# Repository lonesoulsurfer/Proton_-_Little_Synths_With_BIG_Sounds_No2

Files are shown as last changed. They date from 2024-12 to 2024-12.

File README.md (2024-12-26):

# Proton - Little Synths With BIG Sounds #2



This is the 2nd in a series of little synths that I'll be publishing over the next couple builds. Like my Elements synth, I've kept everything as simple as possible on this build so anyone with a soldering iron and basic soldering skills can make it. I've done away with a case and fancy power supplies to keep the build simple.

Props to Synther Jack (https://syntherjack.net/totoro-1-ic-simple-synth/) who designed this amazing little synth. All I've done is redesigned the PCB and created a front panel. I've also done a couple of mods and have included these on this build. Please check out Synther Jacks write up if you want a thorough run through on how the synth works.

The synth runs off 1 IC which is an incredible feat when you consider the amazing sounds this beast can produce. The other amazing thing about this synth is it only needs 2 X AA batteries to power it!

It's a blast to play with and can be connected to a sequencer which really shows off the sounds this little synth is capable of producing. If you don't have a sequencer then don't worry - it's still tonnes of fun to play.

Instructables step by step guide: https://www.instructables.com/Proton-Little-Synths-With-BIG-Sounds-2/

YouTube vid: https://www.youtube.com/watch?v=9Ci_B_42n48



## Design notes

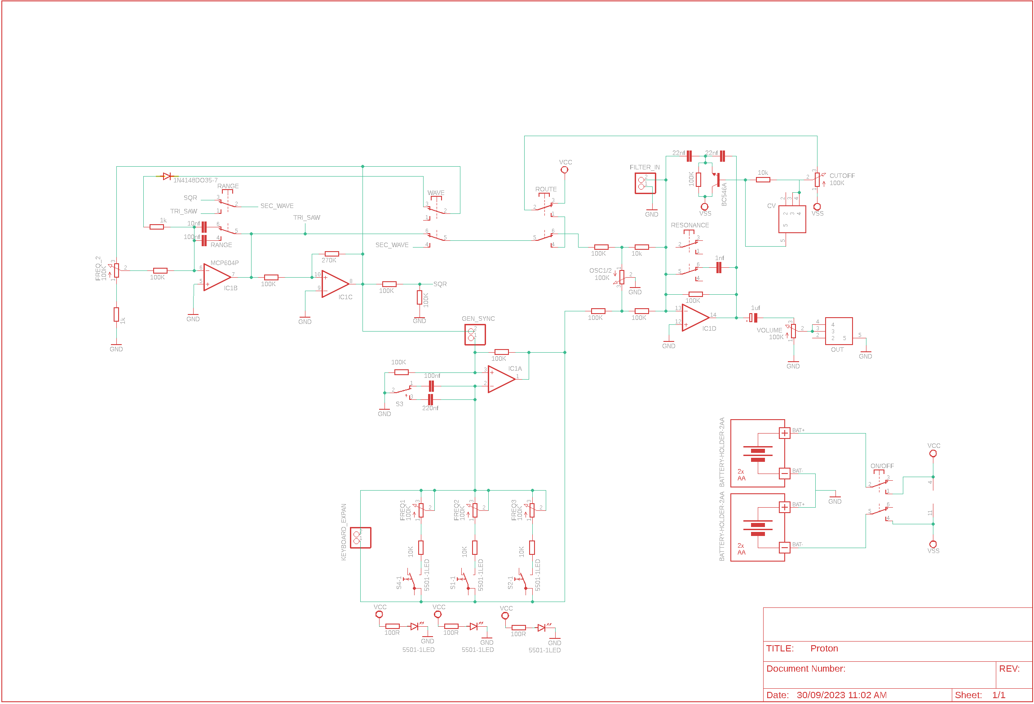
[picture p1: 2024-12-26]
Proton - Schematic.png

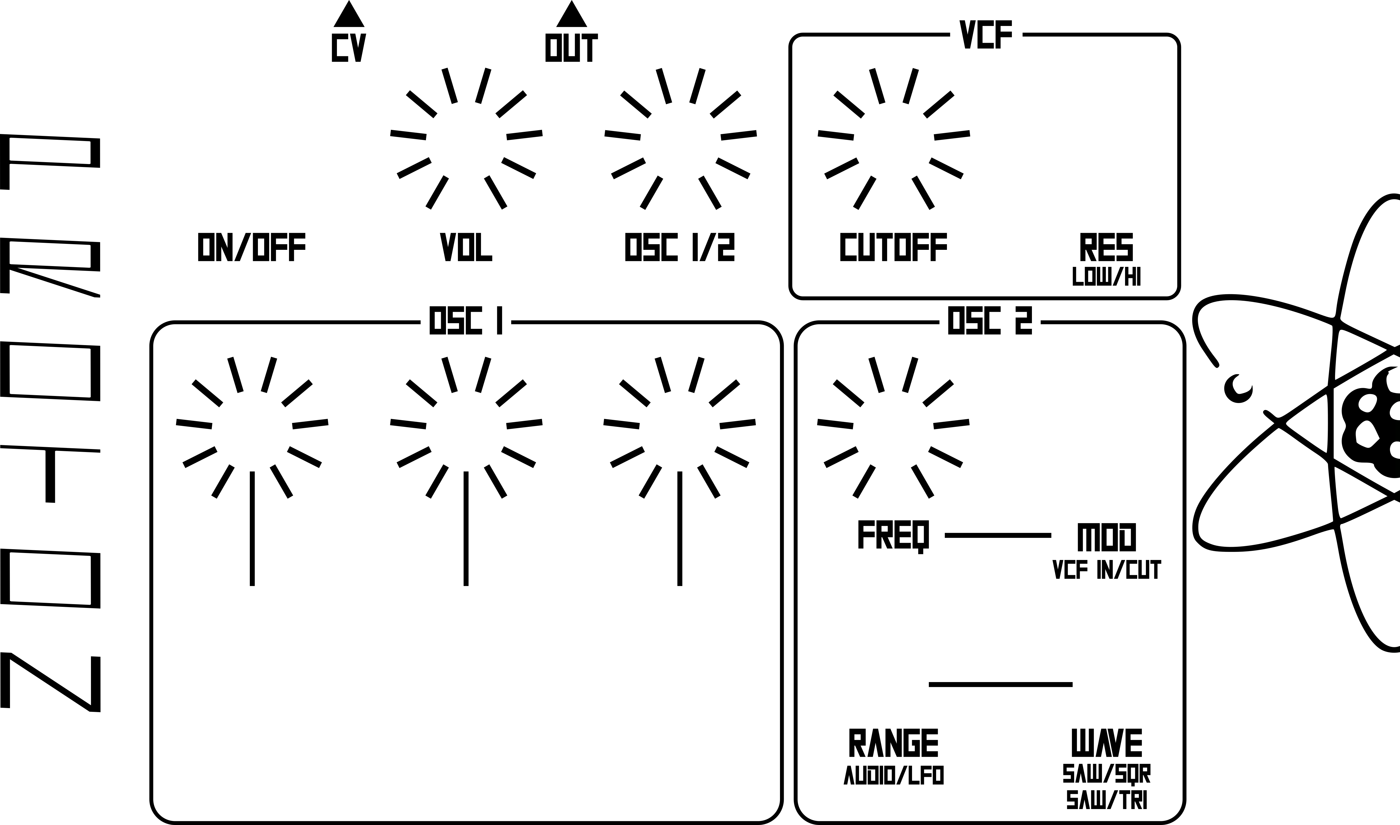
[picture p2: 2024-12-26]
Front Panel Design/Proton - Front Panel.png

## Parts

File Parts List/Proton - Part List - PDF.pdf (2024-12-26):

Part | Type | Value | Qty | Notes | Link | Image
Resistor | Metal Film | 100R | 3 | or just buy them in individual values | link (https://www.aliexpress.com/w/wholesale-resistor-assorted.html?spm=a2g0o.home.search.0) You can buy resistors in assorted lots
| | 1K | 2
| | 10K | 5
| | 100K | 11
| | 270K | 1
Capacitor | Polyester | 1nf | 1 | | link (https://www.aliexpress.com/item/1005001291687251.html?curPageLogUid=RXYDWYWPA8KV)
| | 10nf | 10
| | 22nf | 2
| | 100nf | 2
| | 220nf | 1

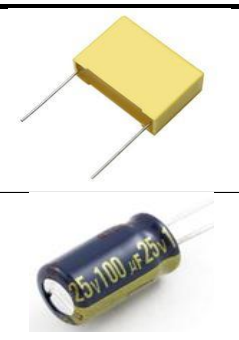
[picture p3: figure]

| electrolytic 16V | 1uf | 1 | any as long as it is over 9V | link (https://www.aliexpress.com/w/wholesale-capacitor-1uf-radial.html?spm=a2g0o.productlist.search.0)

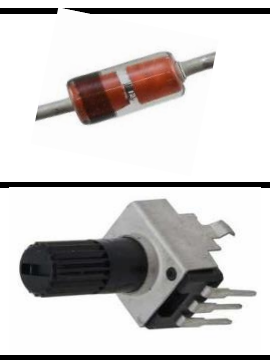
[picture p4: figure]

Diode | 1N4148 | | 1 | | link (https://www.aliexpress.com/w/wholesale-diode-1n4148.html?spm=a2g0o.productlist.search.0)
Potentiometer | 9 mm vertical | 100K | 7 | | link
Audio Jack | PCB Mount | PJ-320A | 2 | | link (https://www.aliexpress.com/item/1005002607946737.html)
IC | MCP6004 | | 1 | Through hole type. | link (https://www.ebay.com.au/sch/i.html?_from=R40&_trksid=p2332490.m570.l1313&_nkw=mcp6004&_sacat=0)
Switches | 6 Pin - 7mm | | 5 | | link (https://www.aliexpress.com/w/wholesale-6-PIN-SWITCH-7mm.html?spm=a2g0o.productlist.search.0)
| Momentary | | 3 | | link (https://www.aliexpress.com/item/1005005461429735.html)
| Slide Switch | | 1 | | link (https://www.aliexpress.com/item/1005005877515591.html?curPageLogUid=p5RxaHHfpDIU)
Transister | BC546 | | 1 | Can use 2N2222 | link (https://www.aliexpress.com/w/wholesale-BC546.html?spm=a2g0o.detail.search.0)
Battery Holder | PCB Mount | AA | 2 | | link (https://www.aliexpress.com/item/1005003776405167.html?curPageLogUid=Q4Qr7hw5smms)

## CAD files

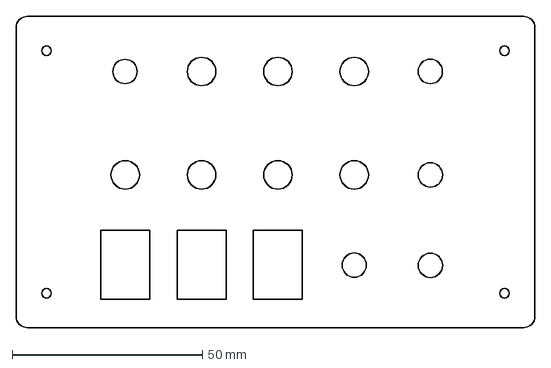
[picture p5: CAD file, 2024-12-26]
Front Panel Design/Proton Fusion - DXF.dxf
136.4 x 81.8 mm

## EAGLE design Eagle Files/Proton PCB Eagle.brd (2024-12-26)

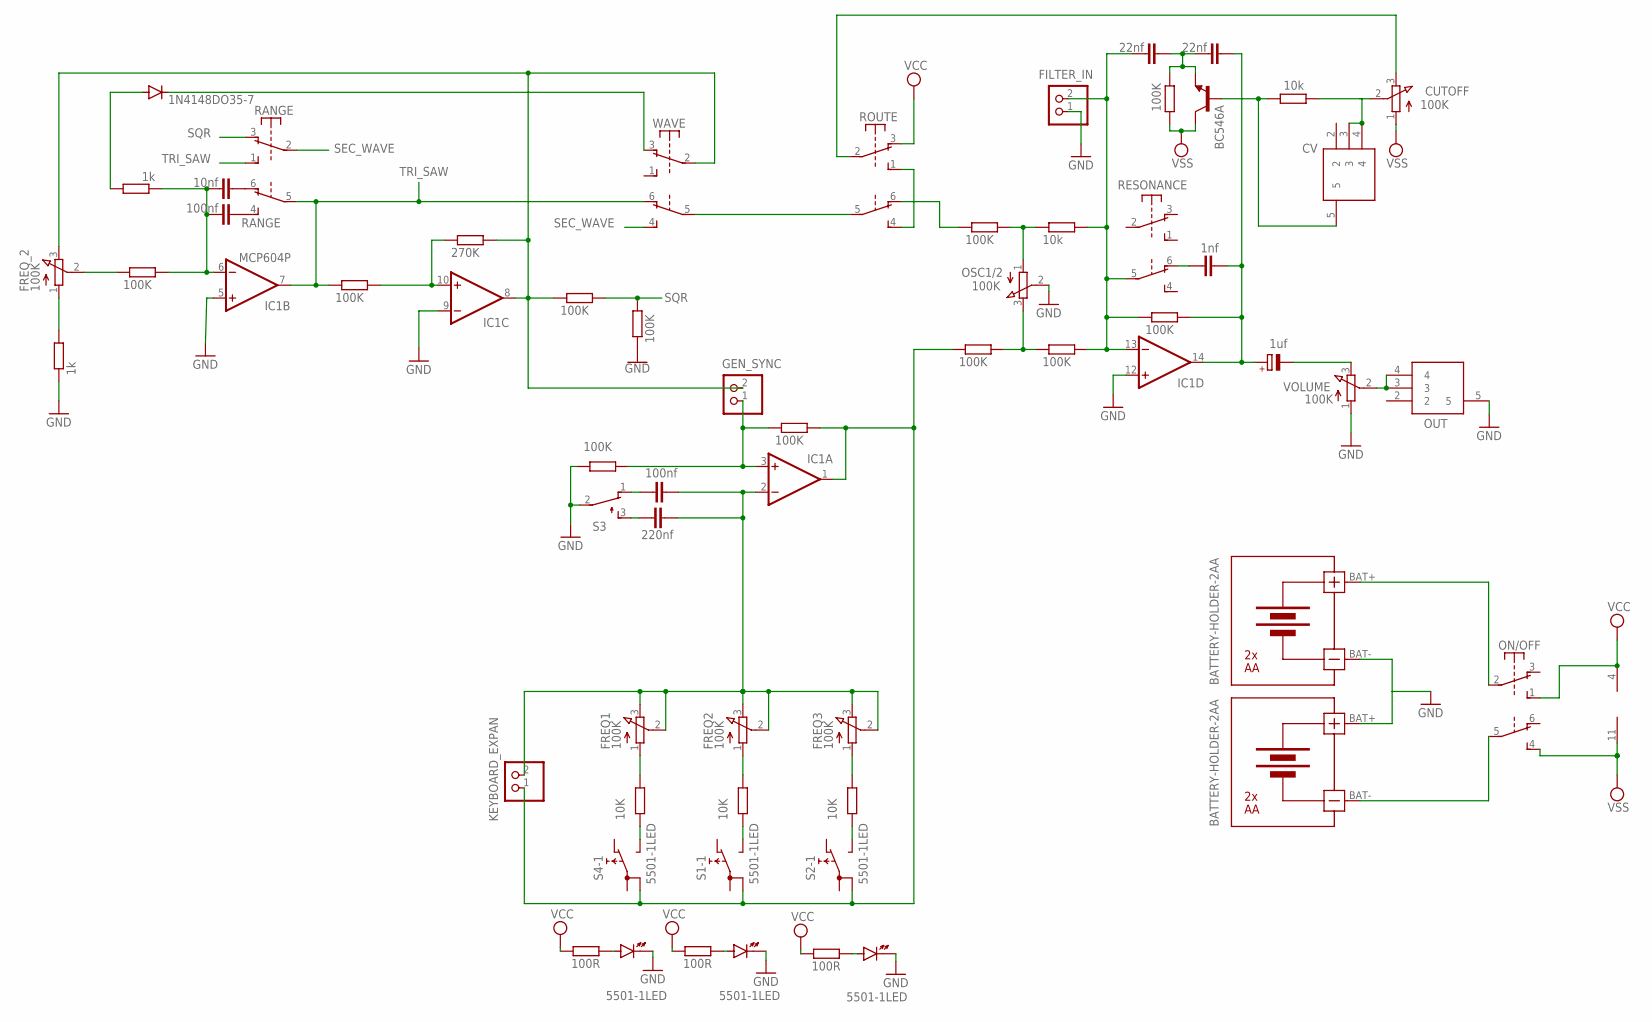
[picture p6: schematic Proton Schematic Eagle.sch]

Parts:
1K, 1K1: 1k; 0207/10
100K, 100K1, 100K3, 100K4, 100K5, 100K7, 100K8, 100K9, 100K11, 100K12, 100K13: 100K; 0207/10
100K2: 270K; 0207/10
100K6, 100K10: 10k; 0207/10
100K14, 100K15, 100K16: 10K; 0207/10
100K18, 100K19, 100K20: 100R; 0207/10
C1, C7: 100nf; C050-024X044
C2: 10nf; C050-024X044
C3, C4: 22nf; C050-024X044
C5: 1nf; C050-024X044
C6: 220nf; C050-024X044
C8: 1uf; E2,5-5
CUTOFF: 100K; EVUFXM
CV: PJ-320A; PJ320A
D1: 1N4148DO35-7; DO35-7
FILTER_IN: PINHD-1X2; 1X02
FREQ1, FREQ2, FREQ3: 100K; EVUFXM
FREQ_2: 100K; EVUFXM
GEN_SYNC: PINHD-1X2; 1X02
IC1: MCP604P; DIL14
KEYBOARD_EXPAN: PINHD-1X2; 1X02
ON/OFF: SWITCH-6PIN
OSC1/2: 100K; EVUFXM
OUT: PJ-320A; PJ320A
Q1: BC546A; TO92-EBC
RANGE: SWITCH-6PIN
RESONANCE: SWITCH-6PIN
ROUTE: SWITCH-6PIN
S1, S2, S4: 5501-1LED
S3: TL32YO; TL3XYO
U$1, U$2: BATTERY-HOLDER-2AA
VOLUME: 100K; EVUFXM
WAVE: SWITCH-6PIN

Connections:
GND: 1K.1, 100K4.1, 100K13.1, FILTER_IN.1, IC1.5 (+IN), IC1.9 (-IN), IC1.12 (+IN), OSC1/2.2 (S), OUT.5, S1.- (K), S2.- (K), S3.2, S4.- (K), U$1.BAT-, U$2.BAT+, VOLUME.1 (A)
unnamed: 100K1.2, 100K2.1, IC1.10 (+IN)
unnamed: 100K.1, FREQ_2.2 (S)
unnamed: 1K.2, FREQ_2.1 (A)
unnamed: C1.2, RANGE.4 (S)
unnamed: C2.2, RANGE.6 (O)
unnamed: 1K1.1, 100K.2, C1.1, C2.1, IC1.6 (-IN)
unnamed: ROUTE.5, WAVE.5
unnamed: 1K1.2, D1.A
unnamed: 100K2.2, 100K3.1, FREQ_2.3 (E), GEN_SYNC.2, IC1.8 (OUT), WAVE.2
unnamed: D1.C, WAVE.3 (O)
unnamed: ROUTE.1 (S), ROUTE.4 (S)
unnamed: 100K5.1, ROUTE.6 (O)
unnamed: 100K5.2, 100K6.1, OSC1/2.1 (A)
unnamed: 100K18.1, S4.+ (A)
unnamed: C8.-, VOLUME.3 (E)
unnamed: 100K9.2, C3.2, C4.1, Q1.E
unnamed: CUTOFF.3 (E), ROUTE.2
unnamed: C5.1, RESONANCE.6 (O)
unnamed: 100K11.2, C4.2, C5.2, C8.+, IC1.14 (OUT)
unnamed: 100K7.2, 100K8.1, OSC1/2.3 (E)
unnamed: 100K6.2, 100K8.2, 100K11.1, C3.1, FILTER_IN.2, IC1.13 (-IN), RESONANCE.5
unnamed: 100K19.1, S1.+ (A)
unnamed: 100K10.1, CV.5, Q1.B
unnamed: 100K20.1, S2.+ (A)
unnamed: 100K12.1, 100K13.2, GEN_SYNC.1, IC1.3 (+IN)
unnamed: ON/OFF.2, U$1.BAT+
unnamed: C6.2, C7.2, FREQ1.2 (S), FREQ1.3 (E), FREQ2.2 (S), FREQ2.3 (E), FREQ3.2 (S), FREQ3.3 (E), IC1.2 (-IN), KEYBOARD_EXPAN.2
unnamed: 100K14.1, S4.NO
unnamed: 100K15.1, S1.NO
unnamed: 100K16.1, S2.NO
unnamed: 100K7.1, 100K12.2, IC1.1 (OUT), KEYBOARD_EXPAN.1, S1.1B, S2.1B, S4.1B
unnamed: 100K14.2, FREQ1.1 (A)
unnamed: 100K15.2, FREQ2.1 (A)
unnamed: 100K16.2, FREQ3.1 (A)
unnamed: ON/OFF.5, U$2.BAT-
unnamed: C6.1, S3.3 (S)
unnamed: C7.1, S3.1 (O)
unnamed: OUT.3, OUT.4, VOLUME.2 (S)
unnamed: 100K10.2, CUTOFF.2 (S), CV.3, CV.4
SEC_WAVE: RANGE.2, WAVE.4 (S)
SQR: 100K3.2, 100K4.2, RANGE.3 (O)
TRI_SAW: 100K1.1, IC1.7 (OUT), RANGE.1 (S), RANGE.5, WAVE.6 (O)
VCC: 100K18.2, 100K19.2, 100K20.2, IC1.4 (V+), ON/OFF.1 (S), ROUTE.3 (O)
VSS: 100K9.1, CUTOFF.1 (A), IC1.11 (V-), ON/OFF.4 (S), Q1.C

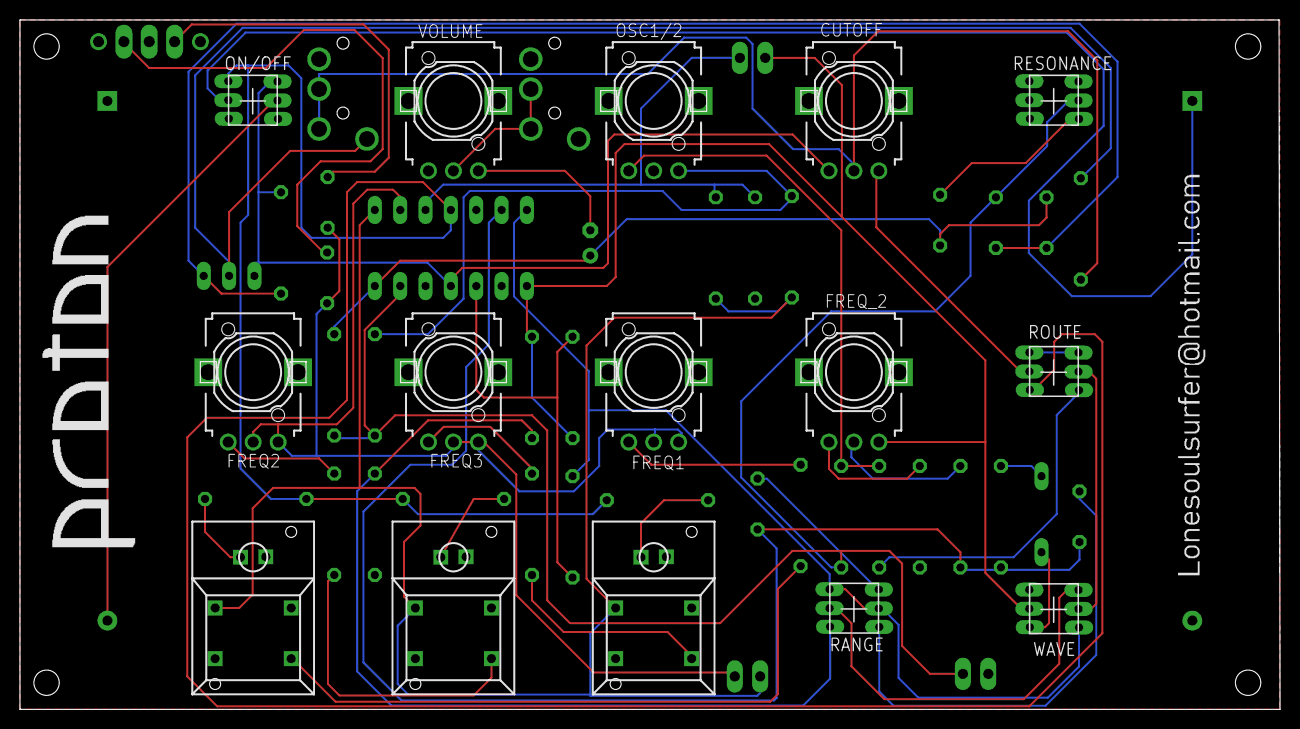
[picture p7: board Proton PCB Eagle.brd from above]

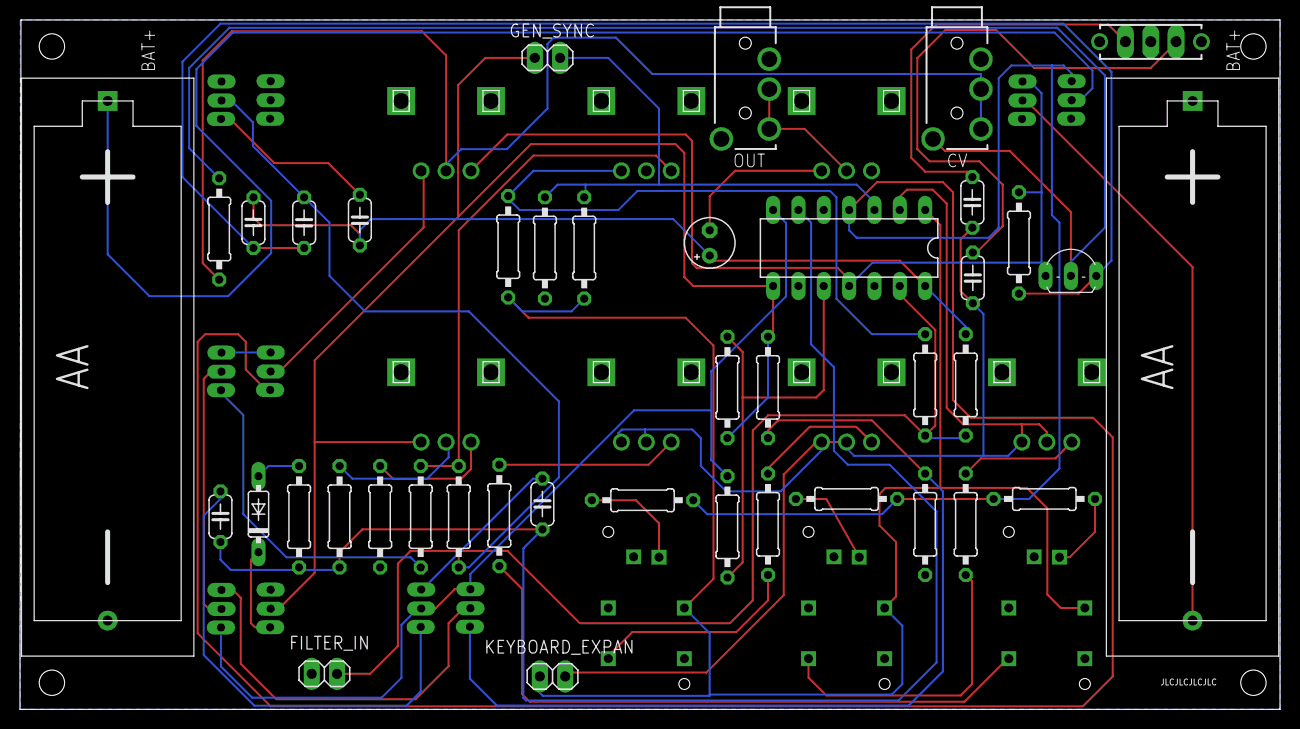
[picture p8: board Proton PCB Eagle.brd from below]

Board: 2 copper layers, 126.3 x 69.1 mm, 56 parts (41 on the bottom side), 45 nets.
